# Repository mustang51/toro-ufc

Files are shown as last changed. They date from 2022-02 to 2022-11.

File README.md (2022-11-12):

# toro-ufc

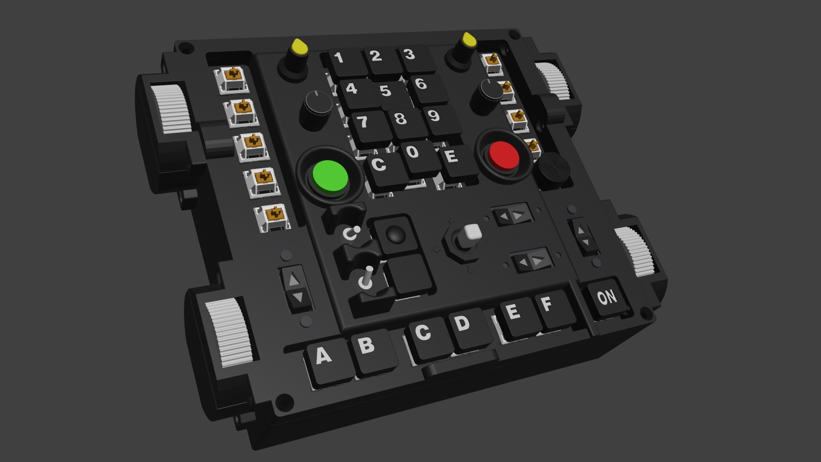
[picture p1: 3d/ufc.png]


USB Up Front Controller, attempting to represent multiple cockpits (F/A-18, F-16, F-15E, A-10C, AV-8B...)

It comprises:

* 12 button numerical pad.
* 10 button in both left and right vertical pads.
* 7 button in horizontal pad.
* 2 rotary encoders with push.
* 2 big buttons.
* 2 small buttons.
* 4 rockers (up/down).
* 2 triple position lever-switches, one with safety cover.
* 4 way dobber lever.
* 6 analog axis (4 lateral, 2 frontal).

## Pin assignments and key matrix

[Pin assignments](doc/pin_assignments.md)

## Bill of materials

* Around 400 grams of PLA for 3D printing.

* 1 STM32F103C6T6 microcontroller.

* 4 ordered PCBs.

* 31 cherry mx switches.

* 2 KY-040 rotary encoders.

* 6 regular 100k potentiometers.

* 12 microswitches.

* 2 MTS-103 ON-OFF-ON lever switches.

* 2 19 mm momentary pushbuttons.

* 12 JST XH 6 pin male PCB connectors.

* 4 JST XH 10 pin male PCB connectors.

* 2 JST XH 8 pin male PCB connectors.

* 1 JST XH 4 pin male PCB connector.

* 44 SMD 0805 diodes.

* 1 JST XH 6 pin 10 mm dual headed cable.

* 1 JST XH 6 pin 20 mm dual headed cable.

* 1 JST XH 8 pin 10 mm dual headed cable.

* 1 JST XH 10 pin 10 mm dual headed cable.

* 8 JST XH 6 pin 20 mm single headed cable.

* 2 JST XJ 10 pin 20 mm single headed cable.

* 1 JST XH 4 pin 20 mm single headed cable.

* 1 mini-USB breakout board.

## Progress pictures

First releases.
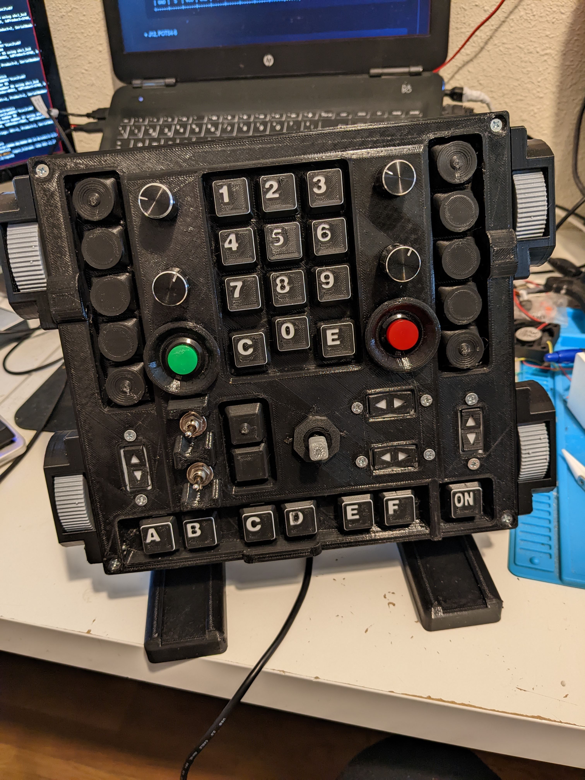
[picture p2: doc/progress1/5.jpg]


Front panel.

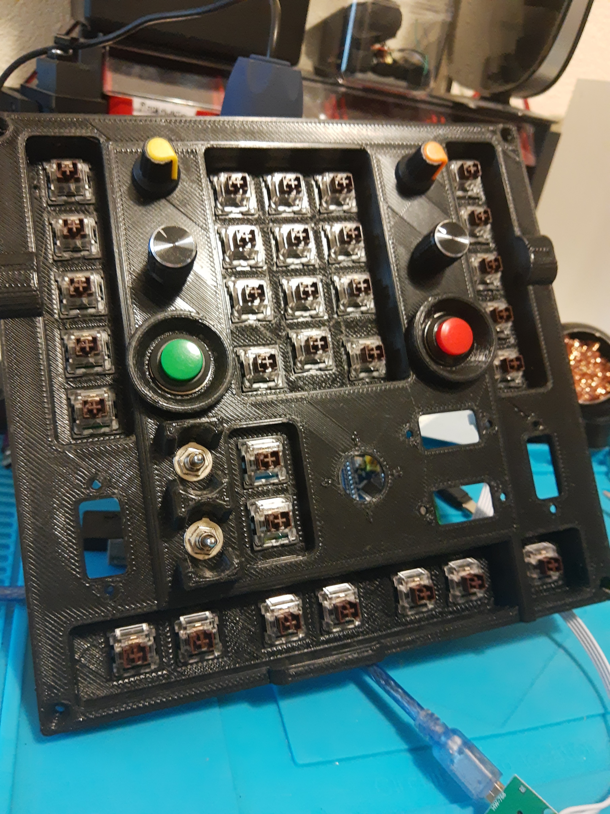
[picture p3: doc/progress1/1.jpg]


Keyswitches PCBs mounted.

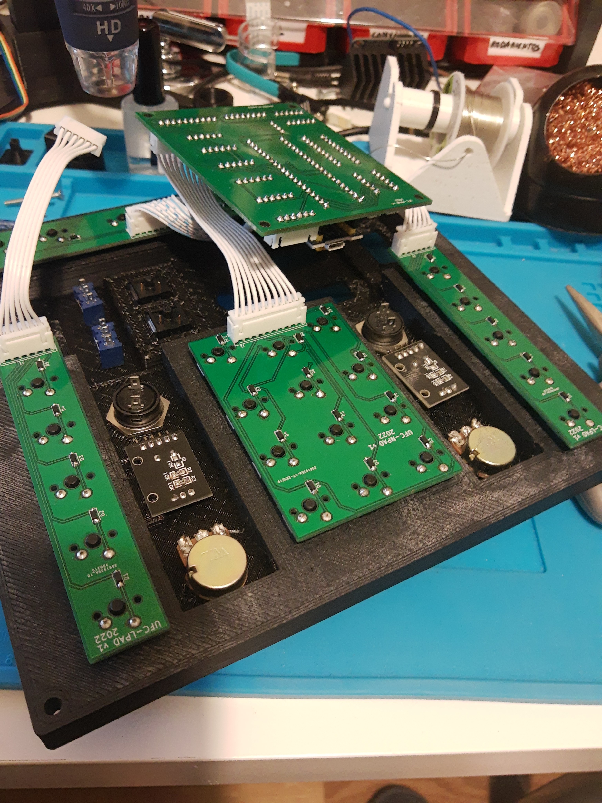
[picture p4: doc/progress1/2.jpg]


First versions of keycaps.

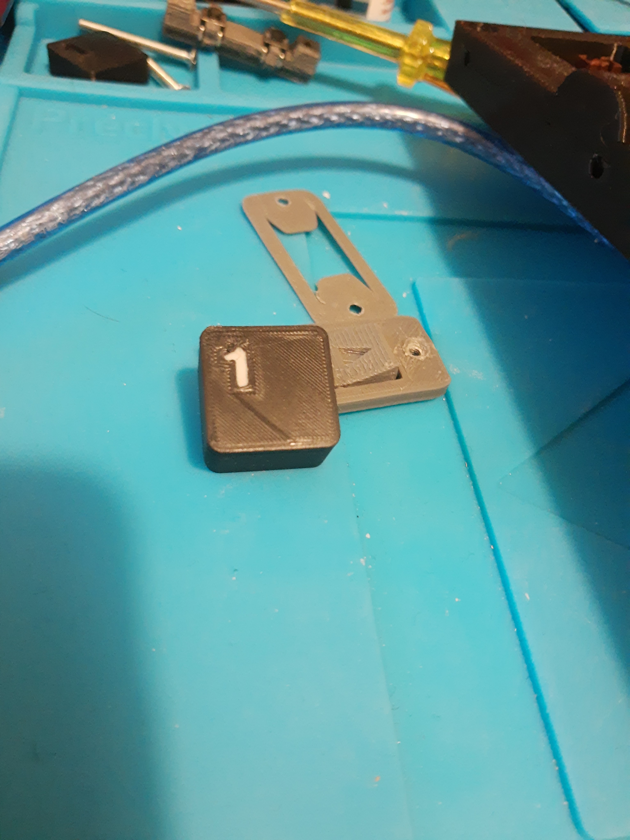
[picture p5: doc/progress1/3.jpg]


Detail of some PCBs.

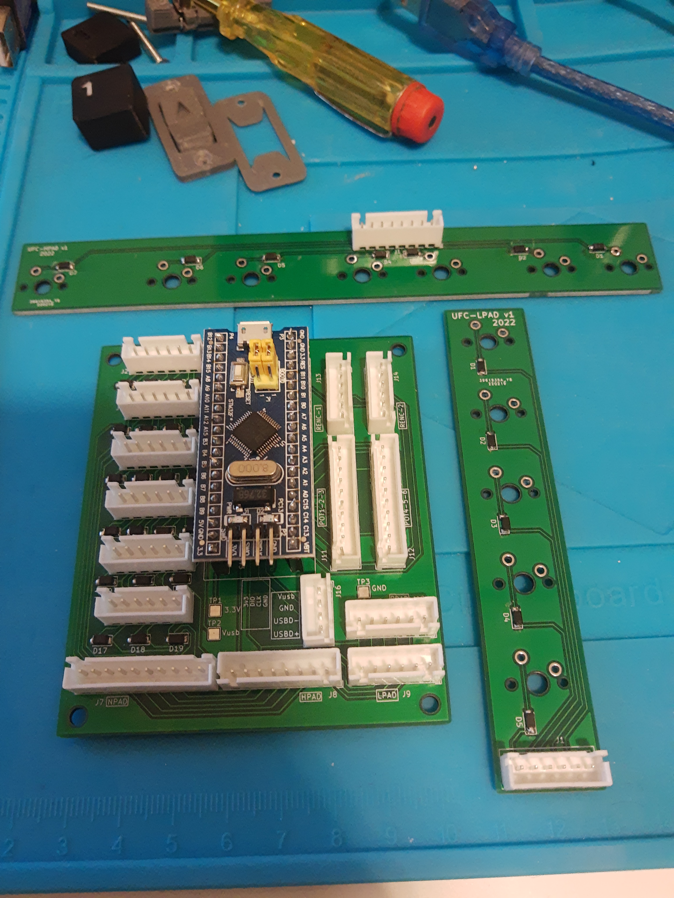
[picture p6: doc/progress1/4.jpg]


[Video of working first prototype.](https://photos.app.goo.gl/QciC3gtiZSFWSCfe9)

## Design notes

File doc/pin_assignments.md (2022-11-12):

## Key matrix

[How does a key matrix work?](https://en.wikipedia.org/wiki/Keyboard_matrix_circuit)

Buttons to scan in the matrix:

* 29 keyboard switches (29)
* 4 rockers (8)
* 1 four-way hat (4)
* 2 triple lever switches (4)
* 2 big buttons (2)
* 2 master mode (2)
* 2 extra unconnected (2)

Total: 51 scan buttons

We will use 8 rows and 7 columns, giving a total of 56 possible buttons.

Rotary encoder buttons will be kept out of the matrix, as the KY-040 designs connect the pushbutton to ground irreversibly.

## Matrix layout

In order to reduce the number of cables and soldering, some switches will be grouped.

The keyboard switches will be grouped into four small PCBs, named: NPAD, LPAD, RPAD and HPAD.

The distribution of rows and columns is as follows:

          R1    R2    R3    R4    R5    R6    R7    R8
        +-----+-----+-----+-----+-----+-----+-----+-----+
     C1 |HPAD |HPAD |HPAD |HPAD |HPAD |HPAD |HPAD |     |
        | F1  | F2  | F3  | F4  | F5  | F6  | ON  |     |
        +-----+-----+-----+-----+-----+-----+-----+-----+
     C2 |NPAD |NPAD |NPAD |NPAD |NPAD |NPAD |NPAD |NPAD |
        |  1  |  2  |  3  |  4  |  5  |  6  |  7  |  8  |
        +-----+-----+-----+-----+-----+-----+-----+-----+
     C3 |NPAD |NPAD |NPAD |NPAD |BIG1 |BIG2 |XTRA1|XTRA2|
        |  9  |  0  | C   | E   |     |     |     |     |
        +-----+-----+-----+-----+-----+-----+-----+-----+
     C4 |LPAD |LPAD |LPAD |LPAD |LPAD |     |     |     |
        | F1  | F2  | F3  | F4  | F5  |     |     |     |
        +-----+-----+-----+-----+-----+-----+-----+-----+
     C5 |RPAD |RPAD |RPAD |RPAD |RPAD |A/A  |A/G  |     |
        | F1  | F2  | F3  | F4  | F5  |     |     |     |
        +-----+-----+-----+-----+-----+-----+-----+-----+
     C6 |RKR1 |RKR1 |RKR2 |RKR2 |RKR3 |RKR3 |RKR4 |RKR4 |
        | UP  | DN  | UP  | DN  | UP  | DN  | UP  | DN  |
        +-----+-----+-----+-----+-----+-----+-----+-----+
     C7 |LVR1 |LVR1 |LVR2 |LVR2 | HAT | HAT | HAT | HAT |
        | UP  | DN  | UP  | DN  |  N  |  S  |  W  |  E  |
        +-----+-----+-----+-----+-----+-----+-----+-----+

* NPAD: numerical pad
* LPAD: left function buttons
* RPAD: right function buttons
* HPAD: bottom horizontal function buttons
* RKRx: rocker buttons
* LVRx: on-off-on lever switches
* HAT : 4-way hat

## Connectors needed

### Hand soldered

* J1, HAT

          C7    R5    R6    R7    R8
        +-----+-----+-----+-----+-----+-----+
        | HAT | HAT | HAT | HAT | HAT |     |
        | CMN |  N  |  S  |  W  |  E  |     |
        +-----+-----+-----+-----+-----+-----+

* J2, RKR1/2

          C6    R1    R2    C6    R3    R4
        +-----+-----+-----+-----+-----+-----+
        |RKR1 |RKR1 |RKR1 |RKR2 |RKR2 |RKR2 |
        | CMN | UP  | DN  | CMN | UP  | DN  |
        +-----+-----+-----+-----+-----+-----+

* J3, RKR3/4

          C6    R5    R6    C6    R7    R8
        +-----+-----+-----+-----+-----+-----+
        |RKR3 |RKR3 |RKR3 |RKR4 |RKR4 |RKR4 |
        | CMN | UP  | DN  | CMN | UP  | DN  |
        +-----+-----+-----+-----+-----+-----+

* J4, LVR1/2

          C7    R1    R2    C7    R3    R4
        +-----+-----+-----+-----+-----+-----+
        |LVR1 |LVR1 |LVR1 |LVR2 |LVR2 |LVR2 |
        | CMN | UP  | DN  | CMN | UP  | DN  |
        +-----+-----+-----+-----+-----+-----+

* J5, A/A, A/G, BIG1

          C5    R6    C5    R7    C3    R5
        +-----+-----+-----+-----+-----+-----+
        | A/A | A/A | A/G | A/G |BIG1 |BIG1 |
        |  1  |  2  |  1  |  2  |  1  |  2  |
        +-----+-----+-----+-----+-----+-----+

* J6, BIG2, XTRA1/2

          C3    R6    C3    R7    C3    R8
        +-----+-----+-----+-----+-----+-----+
        |BIG2 |BIG2 |XTRA1|XTRA1|XTRA2|XTRA2|
        |  1  |  2  |  1  |  2  |  1  |  2  |
        +-----+-----+-----+-----+-----+-----+

* J11, POTS1-3

           1     2     3     4     5     6     7     8     9    10
        +-----+-----+-----+-----+-----+-----+-----+-----+-----+-----+
        | POT3| POT3| POT3| POT2| POT2| POT2| POT1| POT1| POT1|     |
        | GND |  S  | VCC | GND |  S  | VCC | GND |  S  | VCC |     |
        +-----+-----+-----+-----+-----+-----+-----+-----+-----+-----+

* J12, POTS4-6

           1     2     3     4     5     6     7     8     9    10
        +-----+-----+-----+-----+-----+-----+-----+-----+-----+-----+
        | POT6| POT6| POT6| POT5| POT5| POT5| POT4| POT4| POT4|     |
        | GND |  S  | VCC | GND |  S  | VCC | GND |  S  | VCC |     |
        +-----+-----+-----+-----+-----+-----+-----+-----+-----+-----+

* J13, ROTARY1

           1     2     3     4     5     6
        +-----+-----+-----+-----+-----+-----+
        |REN1 |REN1 |REN1 |REN1 |REN1 |     |
        |  C  |  D  |  SW | VCC | GND |     |
        +-----+-----+-----+-----+-----+-----+

* J14, ROTARY2

           1     2     3     4     5     6
        +-----+-----+-----+-----+-----+-----+
        |REN2 |REN2 |REN2 |REN2 |REN2 |     |
        |  C  |  D  |  SW | VCC | GND |     |
        +-----+-----+-----+-----+-----+-----+

* J16, USB

           1     2     3     4
        +-----+-----+-----+-----+
        |VUSB | GND |USBD-|USBD+|
        |     |     |     |     |
        +-----+-----+-----+-----+

Total: 67 connections

### PCB to PCB bridges

* J7, NPAD

          C2    C3    R1    R2    R3    R4    R5    R6    R7    R8
        +-----+-----+-----+-----+-----+-----+-----+-----+-----+-----+
        |  1  |  2  |  3  |  4  |  5  |  6  |  7  |  8  |  9  | 10  |
        |     |     |     |     |     |     |     |     |     |     |
        +-----+-----+-----+-----+-----+-----+-----+-----+-----+-----+

* J8, HPAD

          C1    R1    R2    R3    R4    R5    R6    R7
        +-----+-----+-----+-----+-----+-----+-----+-----+
        |  1  |  2  |  3  |  4  |  5  |  6  |  7  |  8  |
        |     |     |     |     |     |     |     |     |
        +-----+-----+-----+-----+-----+-----+-----+-----+

* J9, LPAD

          C4    R1    R2    R3    R4    R5
        +-----+-----+-----+-----+-----+-----+
        |  1  |  2  |  3  |  4  |  5  |  6  |
        |     |     |     |     |     |     |
        +-----+-----+-----+-----+-----+-----+

* J10, RPAD

          C5    R1    R2    R3    R4    R5
        +-----+-----+-----+-----+-----+-----+
        |  1  |  2  |  3  |  4  |  5  |  6  |
        |     |     |     |     |     |     |
        +-----+-----+-----+-----+-----+-----+

Total: 30 connections

## Pots layout

        +------------------+
        |                  |
     P3 |  P1         P2   | P6
        |                  |
        |                  |
        |                  |
     P4 |                  | P5
        |                  |
        +------------------+

## Rest of connections

* 6 analog axis, two frontal and four lateral.
* 2 rotary encoders, with push.

## Joystick buttons and axis

* Key switches: 1 - 29
* 4 rockers: 30 - 41
* 4 way hat: 42, 43, 44, 45, 46
* 2 triple levers: 47, 48, 49, 50, 51, 52
* 2 big buttons: 53, 54, 55, 56
* 2 extra buttons: 57, 58, 59, 60
* 2 master mode: 61, 62
* 2 rotary encoders: 63, 64, 65, 66, 67, 68
* 6 axis: 69 - 80

## STM32F103C8 pin assignments



           +--------------+
    REN1-C |  PB12  GND   | N/A
    REN1-D |  PB13  GND   | N/A
    REN2-C |  PB14  3V3   | N/A
    REN2-D |  PB15  RST   | N/A
    COL7   |  PA08  PB11  | ROW1
    COL6   |  PA09  PB10  | ROW2
    COL5   |  PA10  PB01  | ROW3
    USB-   |  PA11  PB00  | ROW4
    USB+   |  PA12  PA07  | ROW6
    COL4   |  PA15  PA06  | ROW5
    COL3   |  PB03  PA05  | POT6
    COL2   |  PB04  PA04  | POT5
    COL1   |  PB05  PA03  | POT4
    SCL    |  PB06  PA02  | POT1
    SDA    |  PB07  PA01  | POT2
    ROW7   |  PB08  PA00  | POT3
    ROW8   |  PB09  PC15  | REN1-S
    USB5V  |  5V    PC14  | REN2-S
    N/A    |  GND   PC13  | LED
    N/A    |  3V3   VBAT  | N/A
           +--------------+
             3  PA  PA  G
             V  13  14  N
             3          D

PB03 is being used for TRACE SWO, debug functionality. disableDebugPorts() must be invoked to use it as a normal GPIO.

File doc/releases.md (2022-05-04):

PCBs v1: main PCB is OK
         rest of PCBs v1 need to flip 180 the JST connector

PCBs v2: v1 errors fixed, connect normally.

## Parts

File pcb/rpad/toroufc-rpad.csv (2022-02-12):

Source: | /Users/match/Documents/GitHub/toro-ufc/pcb/rpad/toroufc-rpad.kicad_sch
Date: | 2022 February 12, Saturday 09:43:27
Tool: | Eeschema (6.0.1-0)
Generator: | /Applications/KiCad/KiCad.app/Contents/SharedSupport/plugins/bom_csv_grouped_by_value.py
Component Count: | 11
Individual Components:
Item | Qty | Reference(s) | Value | LibPart | Footprint | Datasheet
 |  | D1 | 1N4148W | Diode:1N4148W | Diode_SMD:D_SOD-123 | https://www.vishay.com/docs/85748/1n4148w.pdf
 |  | D2 | 1N4148W | Diode:1N4148W | Diode_SMD:D_SOD-123 | https://www.vishay.com/docs/85748/1n4148w.pdf
 |  | D3 | 1N4148W | Diode:1N4148W | Diode_SMD:D_SOD-123 | https://www.vishay.com/docs/85748/1n4148w.pdf
 |  | D4 | 1N4148W | Diode:1N4148W | Diode_SMD:D_SOD-123 | https://www.vishay.com/docs/85748/1n4148w.pdf
 |  | D5 | 1N4148W | Diode:1N4148W | Diode_SMD:D_SOD-123 | https://www.vishay.com/docs/85748/1n4148w.pdf
 |  | J10 | Conn_01x06_Male | Connector:Conn_01x06_Male | Connector_JST:JST_XH_B6B-XH-A_1x06_P2.50mm_Vertical | ~
 |  | SW1 | SW_Push | Switch:SW_Push | Button_Switch_Keyboard:SW_Cherry_MX_1.00u_PCB | ~
 |  | SW2 | SW_Push | Switch:SW_Push | Button_Switch_Keyboard:SW_Cherry_MX_1.00u_PCB | ~
 |  | SW3 | SW_Push | Switch:SW_Push | Button_Switch_Keyboard:SW_Cherry_MX_1.00u_PCB | ~
 |  | SW4 | SW_Push | Switch:SW_Push | Button_Switch_Keyboard:SW_Cherry_MX_1.00u_PCB | ~
 |  | SW5 | SW_Push | Switch:SW_Push | Button_Switch_Keyboard:SW_Cherry_MX_1.00u_PCB | ~
Collated Components:
Item | Qty | Reference(s) | Value | LibPart | Footprint | Datasheet
1 | 5 | D1, D2, D3, D4, D5 | 1N4148W | Diode:1N4148W | Diode_SMD:D_SOD-123 | https://www.vishay.com/docs/85748/1n4148w.pdf
2 | 1 | J10 | Conn_01x06_Male | Connector:Conn_01x06_Male | Connector_JST:JST_XH_B6B-XH-A_1x06_P2.50mm_Vertical | ~
3 | 5 | SW1, SW2, SW3, SW4, SW5 | SW_Push | Switch:SW_Push | Button_Switch_Keyboard:SW_Cherry_MX_1.00u_PCB | ~

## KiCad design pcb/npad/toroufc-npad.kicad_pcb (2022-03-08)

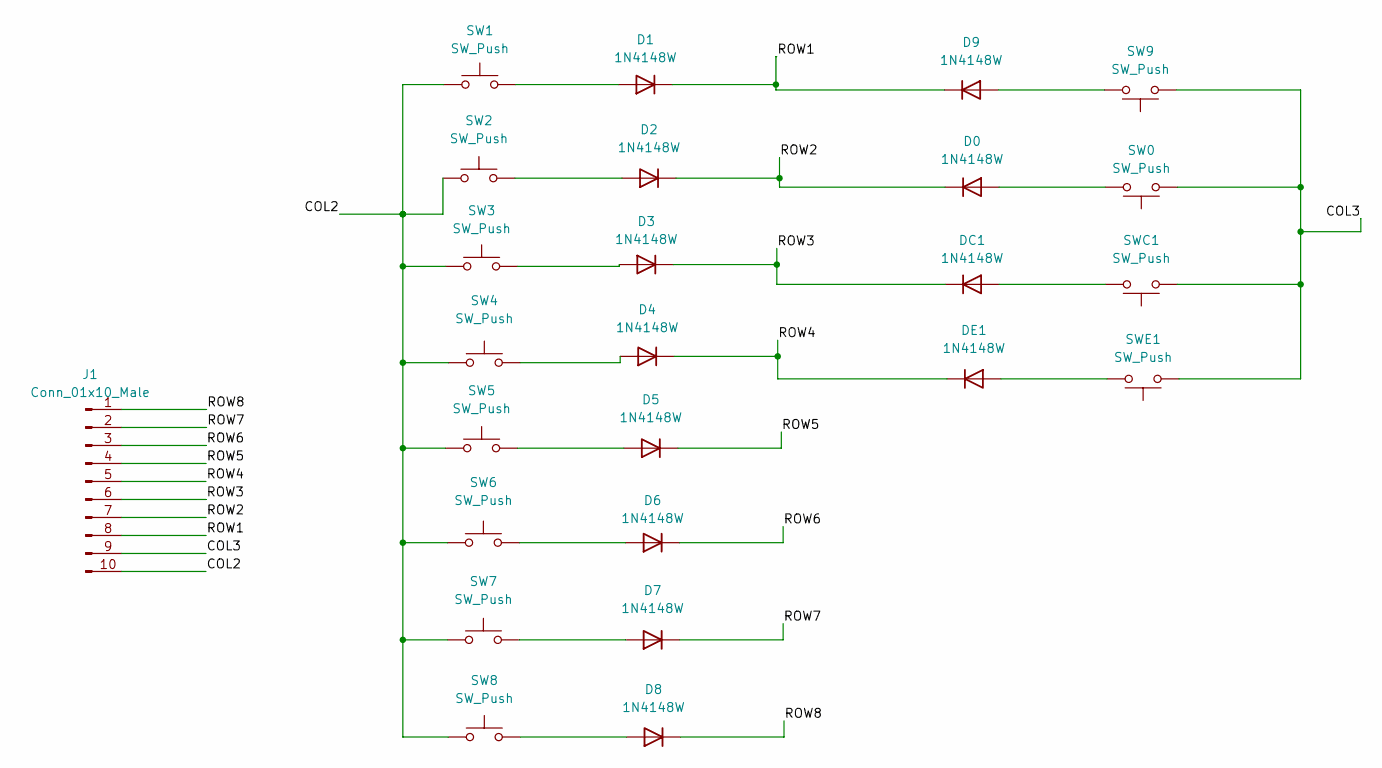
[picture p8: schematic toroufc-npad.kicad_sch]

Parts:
D0, D1, D2, D3, D4, D5, D6, D7, D8, D9: 1N4148W; D_SOD-123
DC1: 1N4148W; D_SOD-123
DE1: 1N4148W; D_SOD-123
J1: Conn_01x10_Male; JST_XH_B10B-XH-AM_1x10_P2.50mm_Vertical
SW0, SW1, SW2, SW3, SW4, SW5, SW6, SW7, SW8, SW9: SW_Push; SW_Cherry_MX_PCB
SWC1: SW_Push; SW_Cherry_MX_PCB
SWE1: SW_Push; SW_Cherry_MX_PCB

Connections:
/COL2: J1.10, SW1.1, SW2.1, SW3.1, SW4.1, SW5.1, SW6.1, SW7.1, SW8.1
/COL3: J1.9, SW0.1, SW9.1, SWC1.1, SWE1.1
/ROW1: D1.1 (K), D9.1 (K), J1.8
/ROW2: D0.1 (K), D2.1 (K), J1.7
/ROW3: D3.1 (K), DC1.1 (K), J1.6
/ROW4: D4.1 (K), DE1.1 (K), J1.5
/ROW5: D5.1 (K), J1.4
/ROW6: D6.1 (K), J1.3
/ROW7: D7.1 (K), J1.2
/ROW8: D8.1 (K), J1.1
unnamed: D0.2 (A), SW0.2
unnamed: D1.2 (A), SW1.2
unnamed: D2.2 (A), SW2.2
unnamed: D3.2 (A), SW3.2
unnamed: D4.2 (A), SW4.2
unnamed: D5.2 (A), SW5.2
unnamed: D6.2 (A), SW6.2
unnamed: D7.2 (A), SW7.2
unnamed: D8.2 (A), SW8.2
unnamed: D9.2 (A), SW9.2
unnamed: DC1.2 (A), SWC1.2
unnamed: DE1.2 (A), SWE1.2

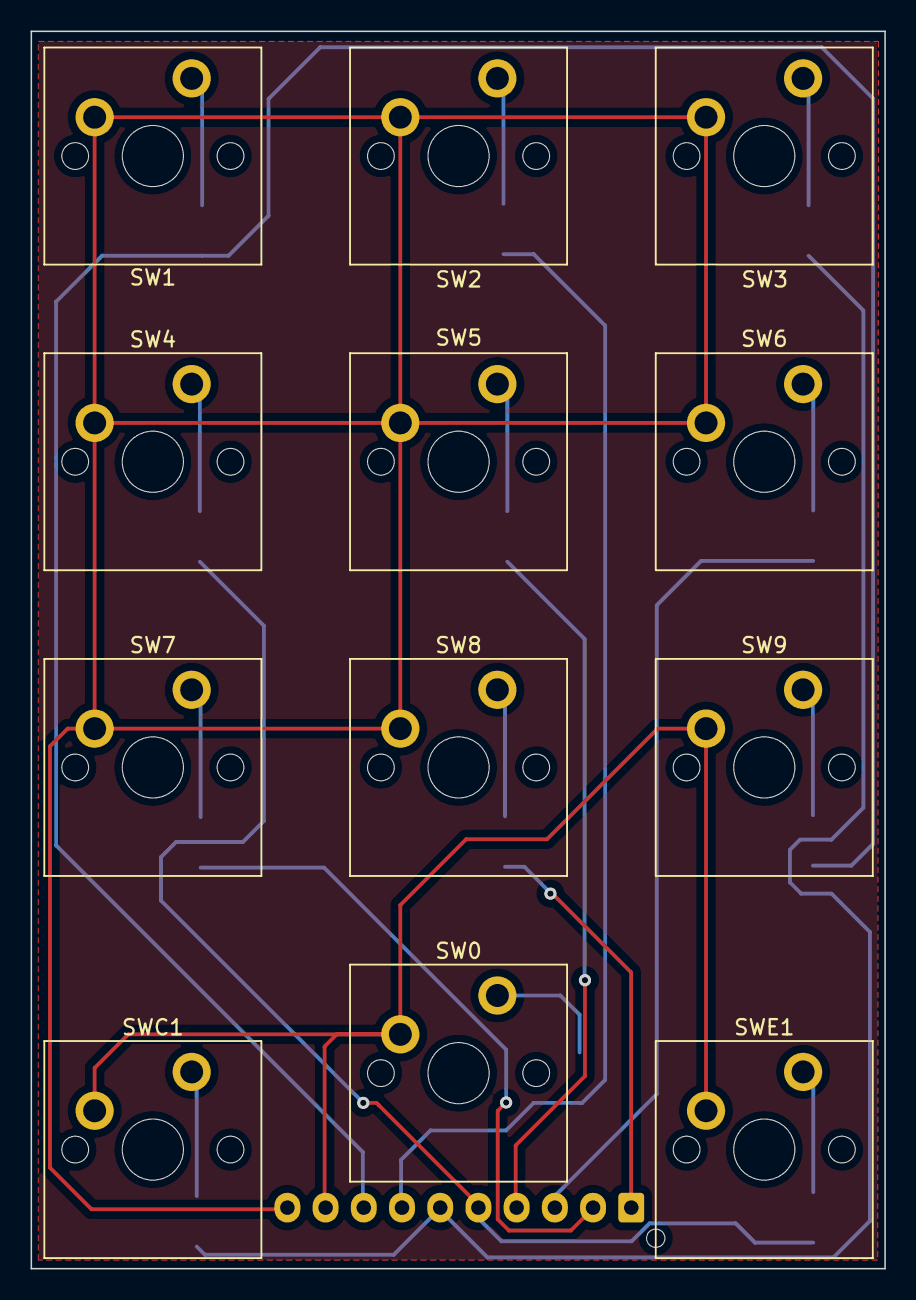
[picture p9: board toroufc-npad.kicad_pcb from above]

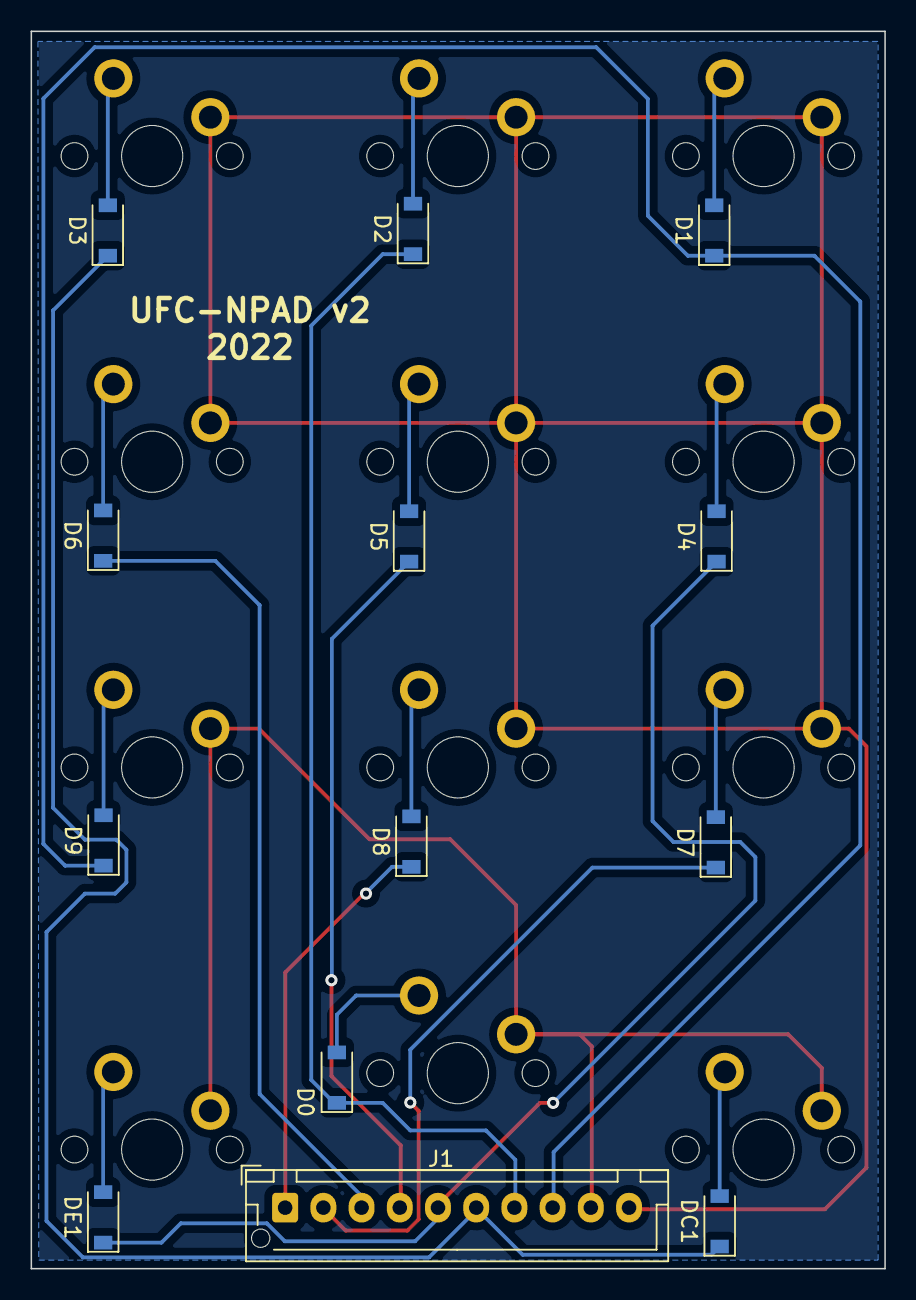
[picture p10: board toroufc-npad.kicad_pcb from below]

Board: 2 copper layers, 55.9 x 80.9 mm, 25 parts (13 on the bottom side), 22 nets.

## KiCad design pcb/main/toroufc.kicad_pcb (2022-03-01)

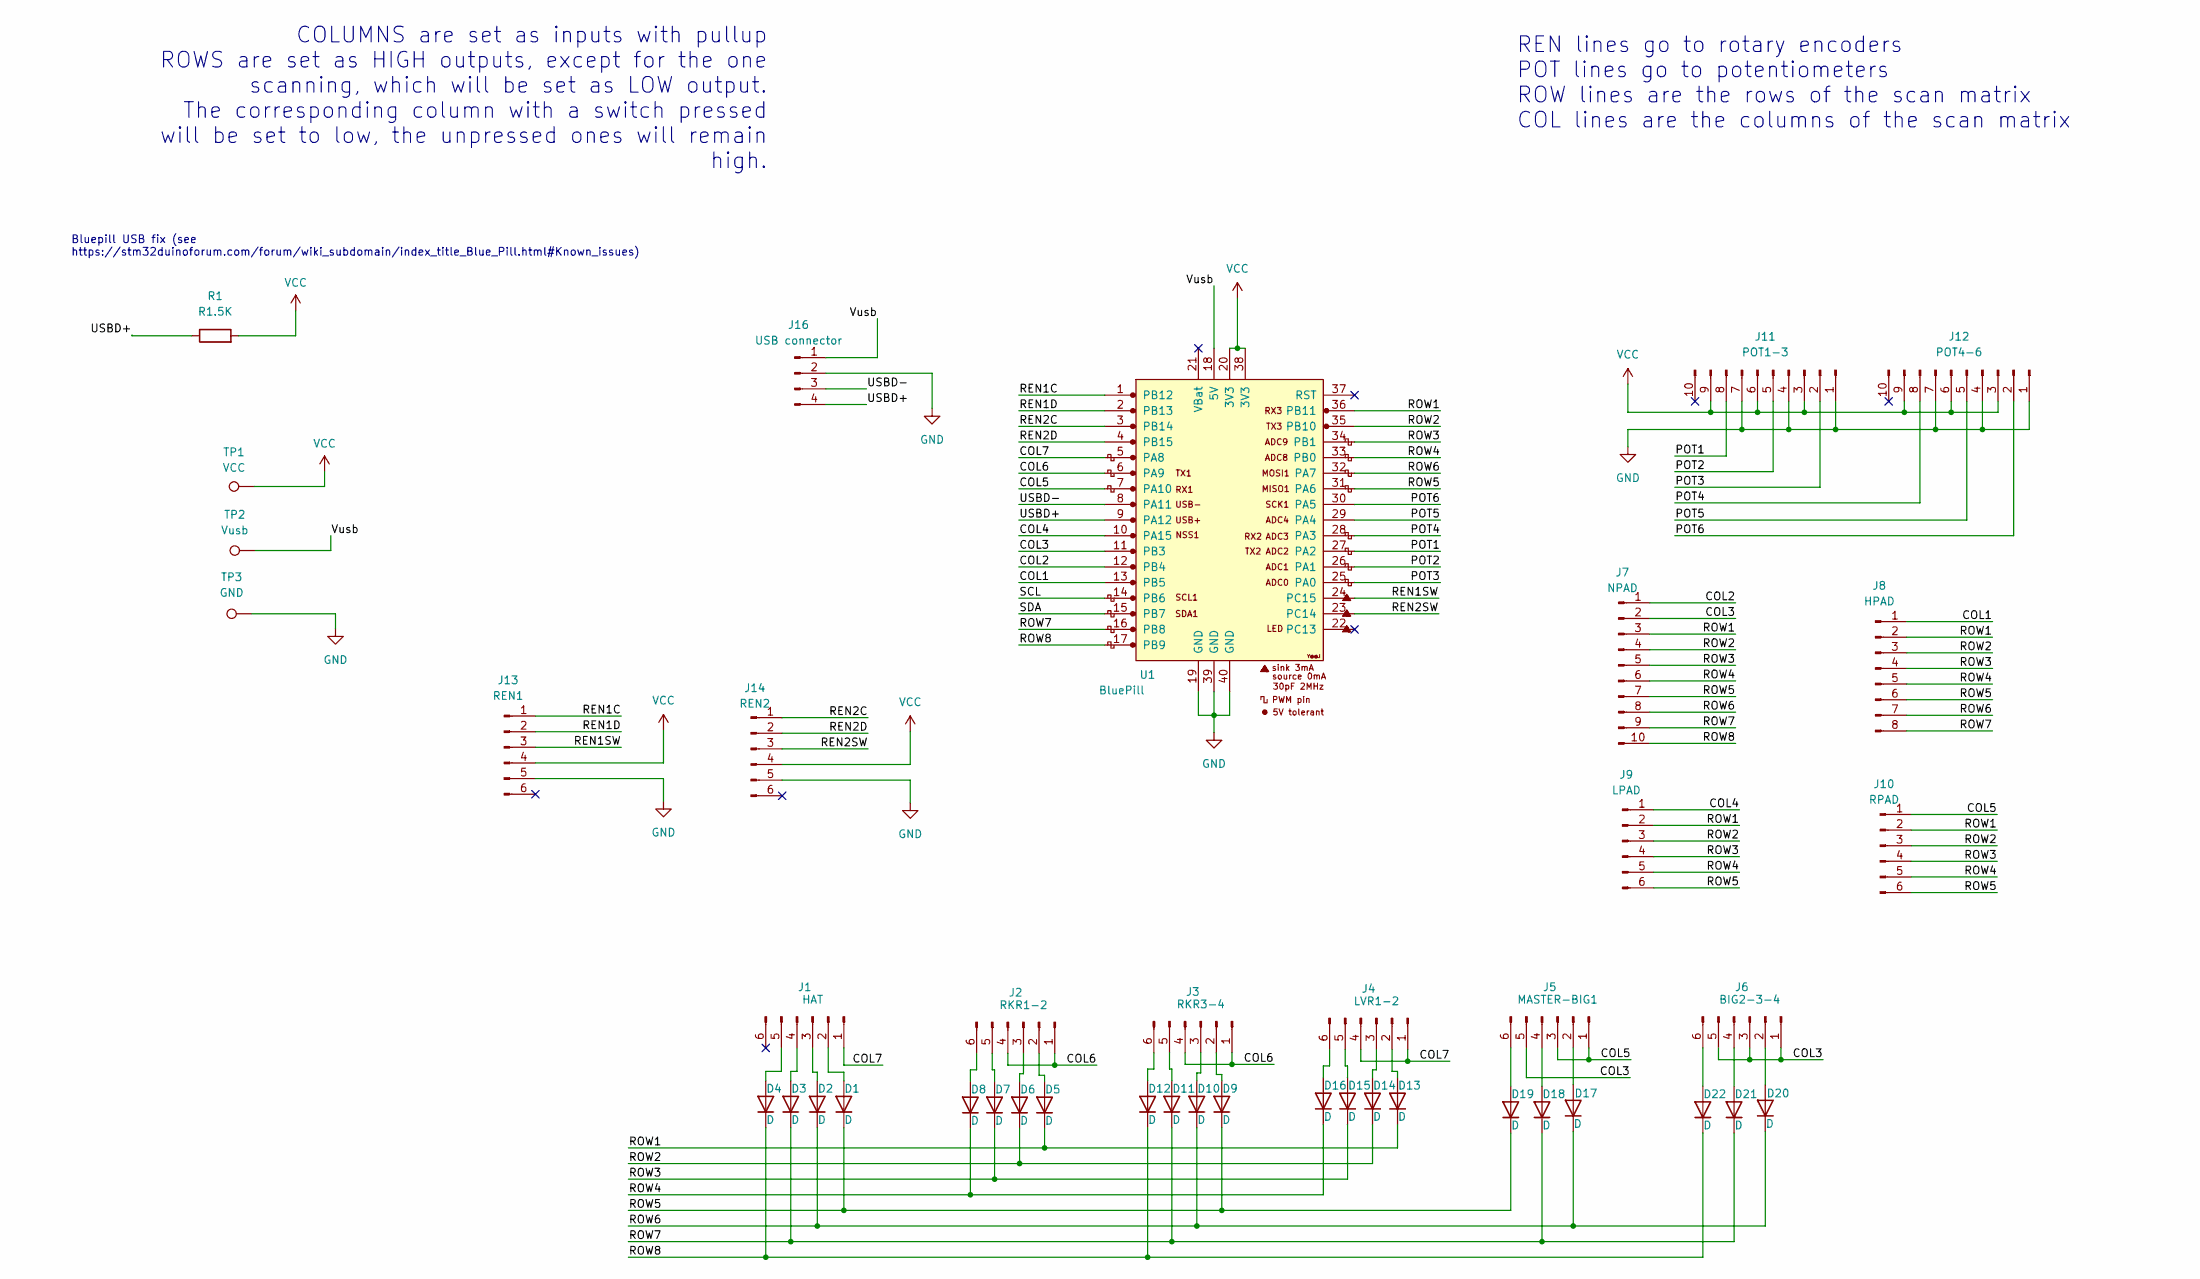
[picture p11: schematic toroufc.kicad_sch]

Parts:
D1, D2, D3, D4, D5, D6, D7, D8, D9, D10, D11, D12, D13, D14, D15, D16, D17, D18, D19, D20, D21, D22: D; D_SOD-123
J1: HAT; JST_XH_B6B-XH-A_1x06_P2.50mm_Vertical
J2: RKR1-2; JST_XH_B6B-XH-A_1x06_P2.50mm_Vertical
J3: RKR3-4; JST_XH_B6B-XH-A_1x06_P2.50mm_Vertical
J4: LVR1-2; JST_XH_B6B-XH-A_1x06_P2.50mm_Vertical
J5: MASTER-BIG1; JST_XH_B6B-XH-A_1x06_P2.50mm_Vertical
J6: BIG2-3-4; JST_XH_B6B-XH-A_1x06_P2.50mm_Vertical
J7: NPAD; JST_XH_B10B-XH-A_1x10_P2.50mm_Vertical
J8: HPAD; JST_XH_B8B-XH-A_1x08_P2.50mm_Vertical
J9: LPAD; JST_XH_B6B-XH-A_1x06_P2.50mm_Vertical
J10: RPAD; JST_XH_B6B-XH-A_1x06_P2.50mm_Vertical
J11: POT1-3; JST_XH_B10B-XH-A_1x10_P2.50mm_Vertical
J12: POT4-6; JST_XH_B10B-XH-A_1x10_P2.50mm_Vertical
J13: REN1; JST_XH_B6B-XH-A_1x06_P2.50mm_Vertical
J14: REN2; JST_XH_B6B-XH-A_1x06_P2.50mm_Vertical
J16: USB connector; JST_XH_B4B-XH-A_1x04_P2.50mm_Vertical
R1: R1.5K; R_0805_2012Metric_Pad1.20x1.40mm_HandSolder
TP1: VCC; TestPoint_Pad_2.0x2.0mm
TP2: Vusb; TestPoint_Pad_2.0x2.0mm
TP3: GND; TestPoint_Pad_2.0x2.0mm
U1: BluePill; YAAJ_BluePill_1

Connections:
/COL1: J8.1, U1.13 (PB5)
/COL2: J7.1, U1.12 (PB4)
/COL3: J5.5, J6.1, J6.3, J6.5, J7.2, U1.11 (PB3)
/COL4: J9.1, U1.10 (PA15)
/COL5: J5.1, J5.3, J10.1, U1.7 (PA10)
/COL6: J2.1, J2.4, J3.1, J3.4, U1.6 (PA9)
/COL7: J1.1, J4.1, J4.4, U1.5 (PA8)
/POT1: J11.8, U1.27 (PA2)
/POT2: J11.5, U1.26 (PA1)
/POT3: J11.2, U1.25 (PA0)
/POT4: J12.8, U1.28 (PA3)
/POT5: J12.5, U1.29 (PA4)
/POT6: J12.2, U1.30 (PA5)
/REN1C: J13.1, U1.1 (PB12)
/REN1D: J13.2, U1.2 (PB13)
/REN1SW: J13.3, U1.24 (PC15)
/REN2C: J14.1, U1.3 (PB14)
/REN2D: J14.2, U1.4 (PB15)
/REN2SW: J14.3, U1.23 (PC14)
/ROW1: D5.1 (K), D13.1 (K), J7.3, J8.2, J9.2, J10.2, U1.36 (PB11)
/ROW2: D6.1 (K), D14.1 (K), J7.4, J8.3, J9.3, J10.3, U1.35 (PB10)
/ROW3: D7.1 (K), D15.1 (K), J7.5, J8.4, J9.4, J10.4, U1.34 (PB1)
/ROW4: D8.1 (K), D16.1 (K), J7.6, J8.5, J9.5, J10.5, U1.33 (PB0)
/ROW5: D1.1 (K), D9.1 (K), D19.1 (K), J7.7, J8.6, J9.6, J10.6, U1.31 (PA6)
/ROW6: D2.1 (K), D10.1 (K), D17.1 (K), D20.1 (K), J7.8, J8.7, U1.32 (PA7)
/ROW7: D3.1 (K), D11.1 (K), D18.1 (K), D21.1 (K), J7.9, J8.8, U1.16 (PB8)
/ROW8: D4.1 (K), D12.1 (K), D22.1 (K), J7.10, U1.17 (PB9)
/SCL: U1.14 (PB6)
/SDA: U1.15 (PB7)
/USBD+: J16.4, R1.1, U1.9 (PA12)
/USBD-: J16.3, U1.8 (PA11)
/Vusb: J16.1, TP2.1, U1.18 (5V)
GND: J11.1, J11.4, J11.7, J12.1, J12.4, J12.7, J13.5, J14.5, J16.2, TP3.1, U1.19 (GND), U1.39 (GND), U1.40 (GND)
unnamed: D1.2 (A), J1.2
unnamed: D2.2 (A), J1.3
unnamed: D3.2 (A), J1.4
unnamed: D4.2 (A), J1.5
unnamed: D5.2 (A), J2.2
unnamed: D6.2 (A), J2.3
unnamed: D7.2 (A), J2.5
unnamed: D8.2 (A), J2.6
unnamed: D9.2 (A), J3.2
unnamed: D10.2 (A), J3.3
unnamed: D11.2 (A), J3.5
unnamed: D12.2 (A), J3.6
unnamed: D13.2 (A), J4.2
unnamed: D14.2 (A), J4.3
unnamed: D15.2 (A), J4.5
unnamed: D16.2 (A), J4.6
unnamed: D17.2 (A), J5.2
unnamed: D18.2 (A), J5.4
unnamed: D19.2 (A), J5.6
unnamed: D20.2 (A), J6.2
unnamed: D21.2 (A), J6.4
unnamed: D22.2 (A), J6.6
VCC: J11.3, J11.6, J11.9, J12.3, J12.6, J12.9, J13.4, J14.4, R1.2, TP1.1, U1.20 (3V3), U1.38 (3V3)

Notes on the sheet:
REN lines go to rotary encoders POT lines go to potentiometers ROW lines are the rows of the scan matrix COL lines are the columns of the scan matrix
Bluepill USB fix (see https://stm32duinoforum.com/forum/wiki_subdomain/index_title_Blue_Pill.html#Known_issues)
COLUMNS are set as inputs with pullup ROWS are set as HIGH outputs, except for the one scanning, which will be set as LOW output. The corresponding column with a switch pressed will be set to low, the unpressed ones will remain high.

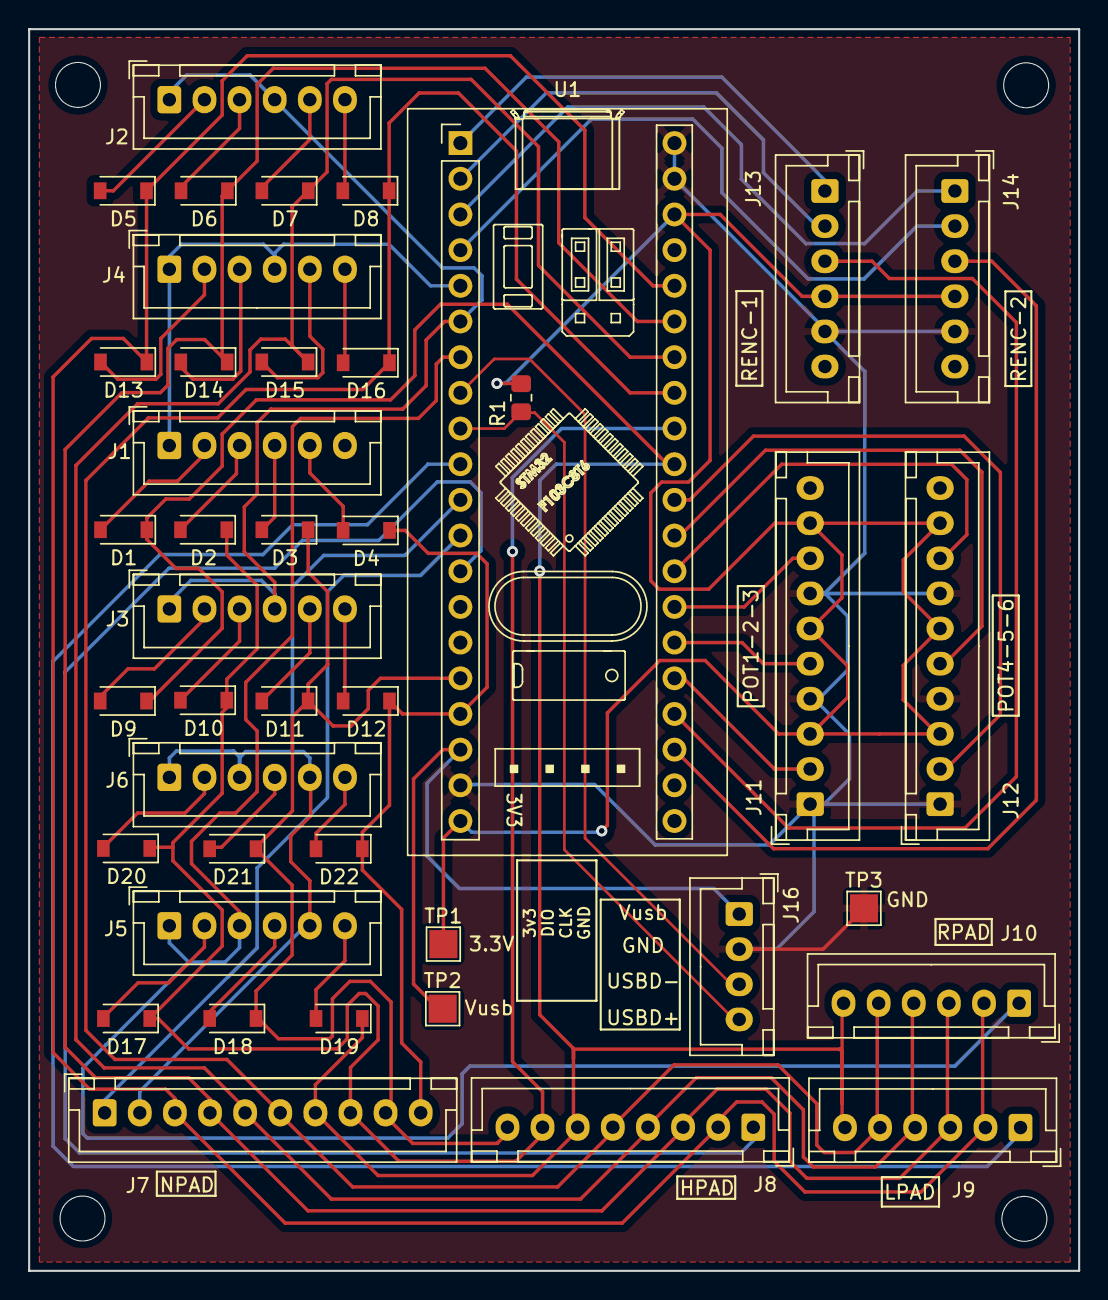
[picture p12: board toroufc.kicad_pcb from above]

Board: 2 copper layers, 74.8 x 88.4 mm, 42 parts (0 on the bottom side), 54 nets.

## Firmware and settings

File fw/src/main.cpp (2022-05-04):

#include <Arduino.h>
#include "ky040.h"
#include "heartbeat.h"
#include "joystick.h"
#include "analog.h"
#include "key_matrix.h"

void setup()
{
	disableDebugPorts();

	heartbeat_setup();
	joystick_setup();
	rotary_setup();
	analog_setup();
	keymatrix_setup();
}

void loop()
{
	heartbeat_loop();
	analog_loop();
	rotary_loop();
	keymatrix_loop();
	joystick_report();  // horribly slow and blocking :(
}

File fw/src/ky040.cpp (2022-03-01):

#include <Arduino.h>

#include "misc.h"
#include "ky040.h"
#include "joystick.h"

static Rotary rotary0(0, PB13, PB12, PC15, 63 , 64 , 65 , true, true);
static Rotary rotary1(1, PB15, PB14, PC14, 66 , 67 , 68 , true, true);

bool Rotary::push(bool right)
{
	if (right)
		curpos++;
	else
		curpos--;

	uint8_t count = (movement_write - movement_read) % MAX_BUFFER;

	if (count == MAX_BUFFER - 1) { // overflow
		overflow = true;
		return false;
	}

	movements[movement_write] = right;
	movement_write		  = (movement_write + 1) % MAX_BUFFER;

	return true;
}

bool Rotary::pull(bool *right)
{
	if (movement_write == movement_read) // empty
		return false;

	*right        = movements[movement_read];
	movement_read = (movement_read + 1) % MAX_BUFFER;

	return true;
}

Rotary::Rotary(unsigned int index,
	       unsigned int clk, unsigned int data,
	       unsigned int sw,
	       unsigned int button_left, unsigned int button_right,
	       unsigned int button_push,
	       bool half_step, bool no_input_pullups) :
	index(index), clk_pin(clk), data_pin(data),
	sw_pin(sw),
	button_left(button_left), button_right(button_right),
	button_push(button_push),
	half_step(half_step), no_input_pullups(no_input_pullups),
	events(0), overflow(false),
	state(IDLE),
	curpos(0),
	filter_data(0), filter_clk(0), filter_sw(0),
	movement_read(0), movement_write(0)
{
}

void Rotary::setup()
{
	if (no_input_pullups) {
		pinMode(clk_pin, INPUT);
		pinMode(data_pin, INPUT);
	} else {
		pinMode(clk_pin, INPUT_PULLUP);
		pinMode(data_pin, INPUT_PULLUP);
	}

	pinMode(sw_pin, INPUT_PULLUP);

	data = (digitalRead(data_pin) == 1) ? FILTER_AMOUNT : -FILTER_AMOUNT;
	clk = (digitalRead(clk_pin) == 1) ? FILTER_AMOUNT : -FILTER_AMOUNT;
}

bool Rotary::filter_sw_fn(bool level)
{
	if (level == HIGH) {
		if (filter_sw < 0) {
			filter_sw = 0;
			return false;
		}
		if (abs(filter_sw) < FILTER_AMOUNT) {
			filter_sw++;
			return false;
		}
	} else {
		if (filter_sw > 0) {
			filter_sw = 0;
			return false;
		}
		if (abs(filter_sw) < FILTER_AMOUNT) {
			filter_sw--;
			return false;
		}
	}
	return true;
}

void Rotary::poll_sw()
{
	bool state = digitalRead(sw_pin);

	if (false == filter_sw_fn(state))
		return;

	Joystick.setButton(button_push, !state);
}

void Rotary::poll_encoder()
{
	char new_data = digitalRead(data_pin);
	char new_clk = digitalRead(clk_pin);

	if ((new_data == 1) && (filter_data < FILTER_AMOUNT))
		filter_data++;
	if ((new_data == 0) && (-filter_data < FILTER_AMOUNT))
		filter_data--;

	if ((new_clk == 1) && (filter_clk < FILTER_AMOUNT))
		filter_clk++;
	if ((new_clk == 0) && (-filter_clk < FILTER_AMOUNT))
		filter_clk--;

	if ((filter_data != FILTER_AMOUNT) && (filter_data != -FILTER_AMOUNT))
		new_data = data;
	else
		new_data = filter_data;

	if ((filter_clk != FILTER_AMOUNT) && (filter_clk != -FILTER_AMOUNT))
		new_clk = clk;
	else
		new_clk = filter_clk;

	if ((new_data == data) && (new_clk == clk))
		return;

	if (half_step) {
		if (new_data != new_clk) {
			events++;
			if (new_data != data)
				push(false);
			else
				push(true);
		}
	}

	data = new_data;
	clk  = new_clk;
}

void Rotary::poll_machine()
{
	unsigned long now = millis();
	if (state != IDLE) {
		// Button is held left or right, do we have to hold it down a bit?
		if ((now - activity_ms) < TIME_UP)
			return;
	}

	switch(state) {
	case IDLE:
	{
		bool activity;
		bool move_right;

		activity = pull(&move_right);

		if (!activity) {
			if (overflow) {
				overflow = false;
				Joystick.setButton(button_right, false);
				Joystick.setButton(button_left, false);
			}
			return; // no news
		}

		if (move_right) {
			state = RIGHT_PRESSED;
			if (!overflow)
				Joystick.setButton(button_right, true);
		} else {
			state = LEFT_PRESSED;
			if (!overflow)
				Joystick.setButton(button_left, true);
		}
		activity_ms = now;
	}
	break;
	case RIGHT_PRESSED:
		if (!overflow) {
			Joystick.setButton(button_right, false);
		}
		state = IDLE;
		break;
	case LEFT_PRESSED:
		if (!overflow) {
			Joystick.setButton(button_left, false);
		}
		state = IDLE;
		break;
	}

	return;
}

static void rotary_loop_sw(void)
{
	static unsigned long next_millis = 0;
	if (! time_expired_from(millis(), next_millis))
		return;
	next_millis += Rotary::POLL_SW_MS;

	rotary0.poll_sw();
	rotary1.poll_sw();

	return;
}

static void rotary_loop_enc(void)
{
	static unsigned long next_millis = 0;
	if (! time_expired_from(millis(), next_millis))
		return;
	next_millis += Rotary::POLL_ROTARY_MS;

	rotary0.poll_encoder();
	rotary0.poll_machine();

	rotary1.poll_encoder();
	rotary1.poll_machine();

	return;
}

void rotary_setup()
{
	rotary0.setup();
	rotary1.setup();
}

void rotary_loop(void)
{
	rotary_loop_sw();
	rotary_loop_enc();
}

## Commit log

2022-02-07 Adding pcb skeleton.
    [toroufc.kicad_pcb, toroufc.kicad_sch, toroufc.sch]
2022-02-07 Moving stuff.
    [toroufc.kicad_pcb, toroufc.kicad_sch]
2022-02-07 More rinsing.
    [toroufc.kicad_sch]
2022-02-08 Pin assignments rework.
2022-02-08 More work on pin assignments.
2022-02-08 Pin assignments.
2022-02-08 More tidying up.
    [toroufc.kicad_sch, toroufc.sch]
2022-02-08 Starting with the PCB.
    [toroufc.kicad_pcb, toroufc.kicad_sch]
2022-02-09 First PCB that passes DRC
    [toroufc.kicad_pcb, toroufc.kicad_sch]
2022-02-09 Main PCB looking good.
    [toroufc.kicad_pcb]
2022-02-09 Adding 3d models to pcb
2022-02-09 Add mounting holes to pcb.
    [toroufc.kicad_pcb]
2022-02-10 Changing pcb connectors to JST XH
    [toroufc.kicad_pcb, toroufc.kicad_sch]
2022-02-11 Fixing some lanes.
    [toroufc.kicad_pcb, toroufc.kicad_sch]
2022-02-11 Adding directories for five pcbs.
    [toroufc-hpad.kicad_pcb, toroufc-hpad.kicad_sch, toroufc-lpad.kicad_pcb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]
2022-02-11 Added LPAD pcb.
    [toroufc-lpad.kicad_pcb, toroufc-lpad.kicad_sch]
2022-02-11 Missing model paths.
    [toroufc-lpad.kicad_pcb]
2022-02-12 First RPAD
    [toroufc-rpad.csv, toroufc-rpad.kicad_pcb, toroufc-rpad.kicad_sch]
2022-02-12 Minor fixes
    [toroufc-rpad.csv]
2022-02-12 Added test points, reduced size, removed i2c, labels, bluepill fix.
    [toroufc.kicad_pcb, toroufc.kicad_sch]
2022-03-01 First production
    [toroufc-hpad.kicad_pcb, toroufc-hpad.kicad_sch, toroufc-lpad.kicad_pcb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]
2022-03-08 Preparing PCBs v2
    [toroufc-hpad.kicad_pcb, toroufc-hpad.kicad_sch, toroufc-lpad.kicad_pcb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]
2022-05-04 Updating to pcbs v2
2022-05-04 Removing lateral buttons, now they are extra buttons...
2022-05-04 Adding simple BOM and progress.
2022-06-27 First prototype.
